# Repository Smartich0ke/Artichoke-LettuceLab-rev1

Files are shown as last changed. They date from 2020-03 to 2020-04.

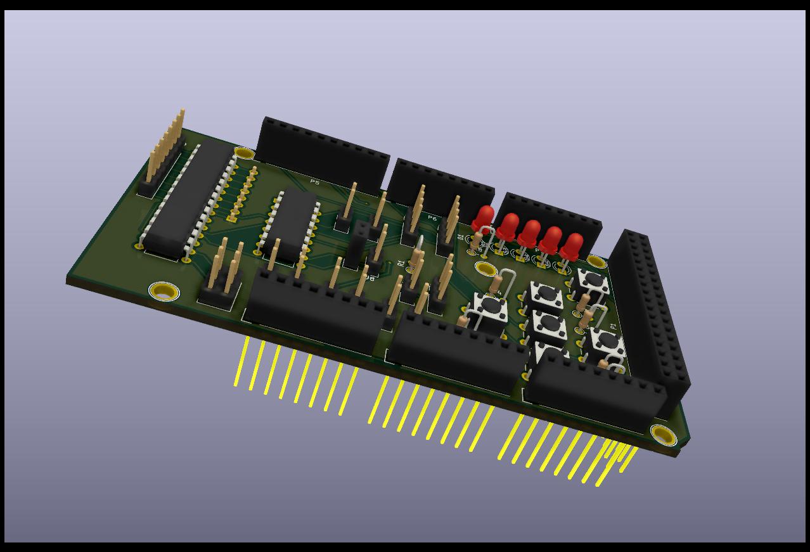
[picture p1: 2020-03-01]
pcb-files/megasheild.jpg

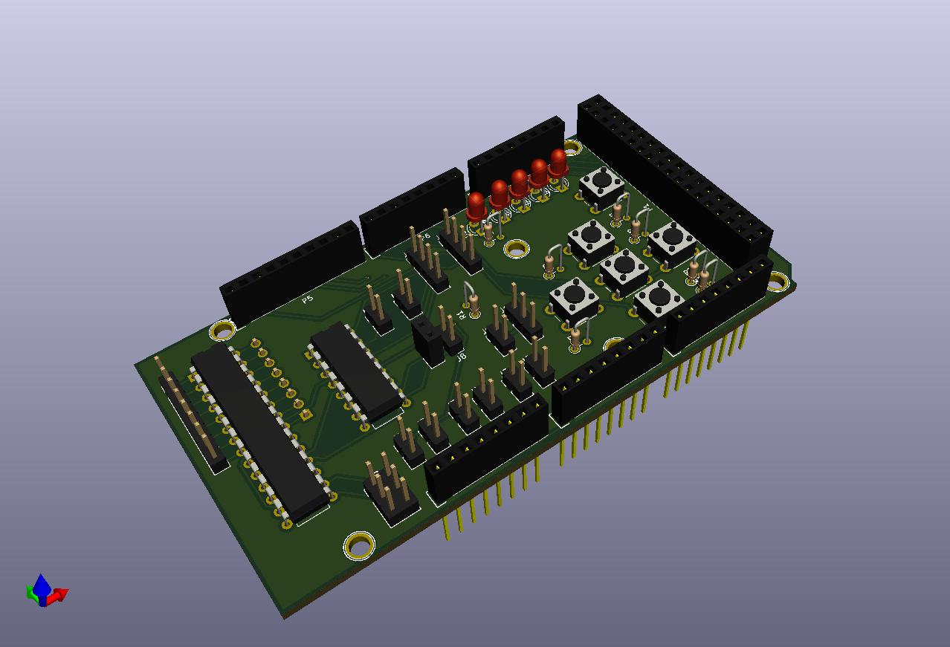
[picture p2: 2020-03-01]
pcb-files/megasheild5.jpg

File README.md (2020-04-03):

# Artichoke LettuceLab rev1

For more information please see my website at: https://hackaday.io/project/170160-artichoke-lettucelab-rev-10#header

Please feel free to join this repository if you are interested or email me at: pitsnthings@gmail.com

The Artichoke LettuceLab Arduino Mega sheild is designed to make the construction of small arduino robots much easier and less time consuming. It can drive 2 motors (or one stepper motor), a I2C interfaced LCD display, an ultrasonic distance sensor, an LDR sensor, 2 headlights, 2 blinkers, 2 tail lights, 5 LEDS, 6 buttons and it even includes a MCP23017 GPIO expander to give you another 16 I/O pins.

FILES:

lettucelab-master.zip : All nececarry gerber files compressed into a zip file.

pcb-files : all kicad pcb files, inside that is "gerbers1.0"  which has all the gerbers in it.

wheels1.0.ino : Example Arduino sketch for wheels and lights.

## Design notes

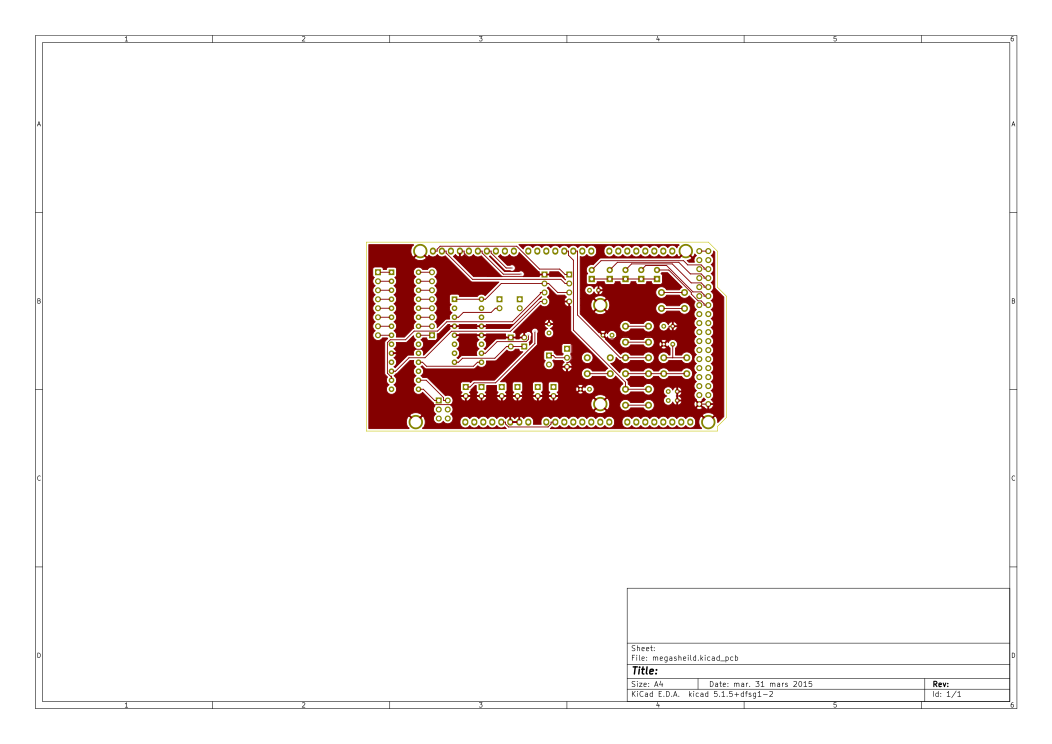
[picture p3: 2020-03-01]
pcb-files/megasheild-F_Cu.png

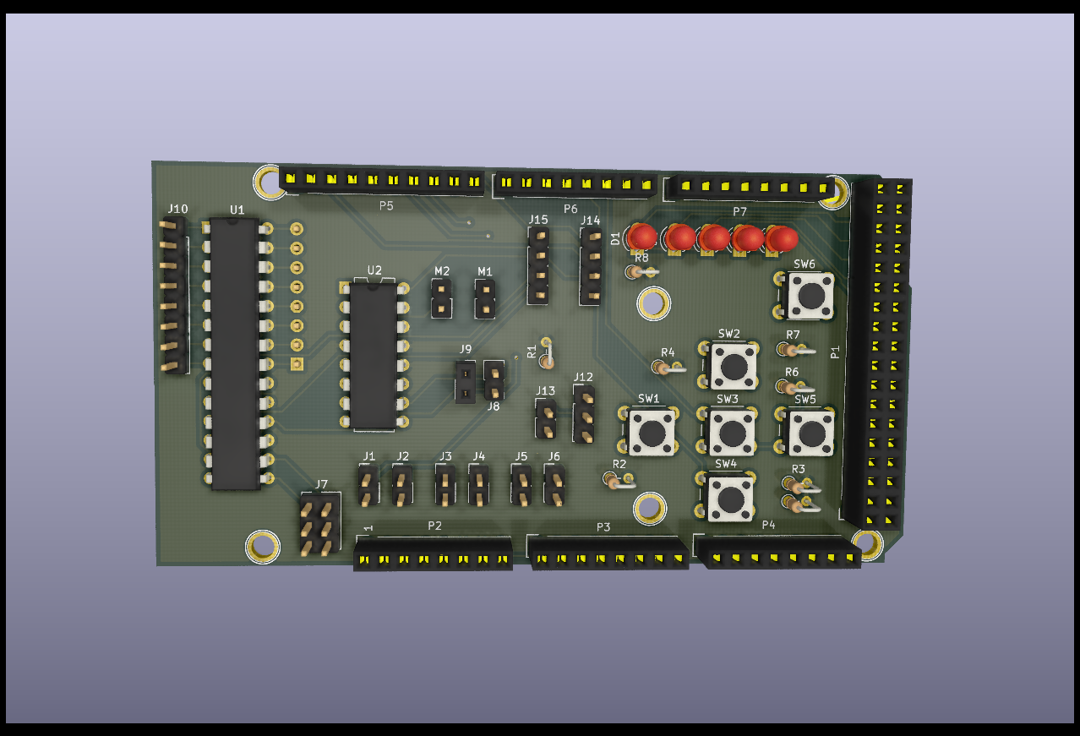
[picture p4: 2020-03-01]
pcb-files/megasheild3.png

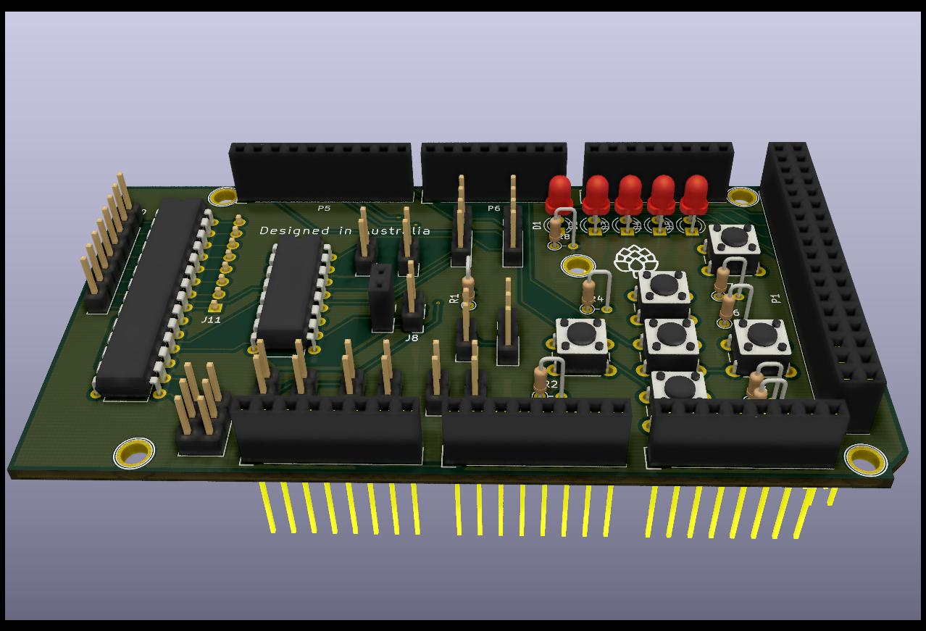
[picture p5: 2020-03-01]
pcb-files/background.jpg

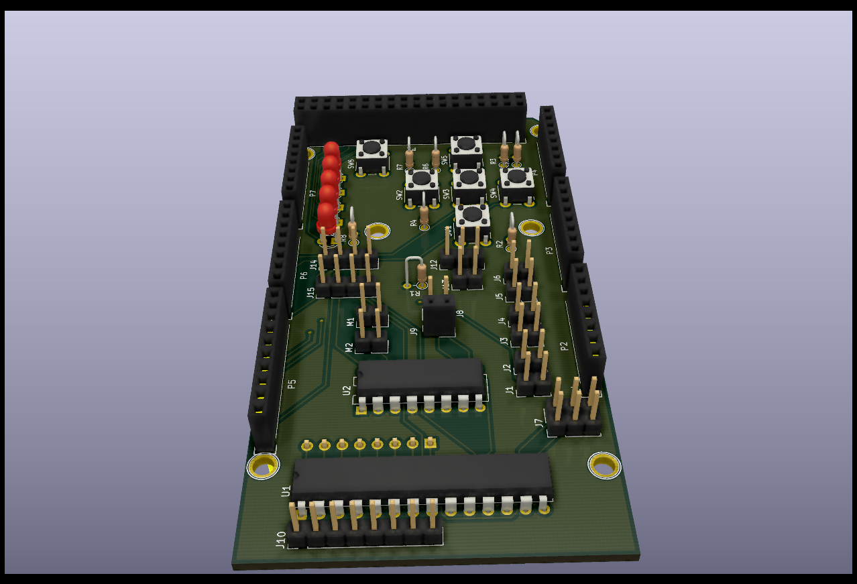
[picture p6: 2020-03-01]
pcb-files/megasheild2.png

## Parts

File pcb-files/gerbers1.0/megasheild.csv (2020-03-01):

Id | Designator | Package | Quantity | Designation | Supplier and ref
1 | G*** | 10 | 1 | LOGO
2 | U2 | DIP-16_W7.62mm | 1 | L293D
3 | P1 | Socket_Strip_Arduino_2x18 | 1 | Digital
4 | P2 | Socket_Strip_Arduino_1x08 | 1 | Power
5 | P3,P4 | Socket_Strip_Arduino_1x08 | 2 | Analog
6 | P5 | Socket_Strip_Arduino_1x10 | 1 | PWM
7 | P6 | Socket_Strip_Arduino_1x08 | 1 | PWM
8 | P7 | Socket_Strip_Arduino_1x08 | 1 | Communication
9 | P8,P9,P10,P11,P12,P13 | Arduino_1pin | 6 | CONN_01X01
10 | D1,D2,D3,D4,D5 | LED_D3.0mm | 5 | LED
11 | J1 | PinHeader_1x02_P2.54mm_Vertical | 1 | leftheadlight
12 | J2 | PinHeader_1x02_P2.54mm_Vertical | 1 | rightheadlight
13 | J3 | PinHeader_1x02_P2.54mm_Vertical | 1 | leftblinker
14 | J4 | PinHeader_1x02_P2.54mm_Vertical | 1 | rightblinker
15 | J5 | PinHeader_1x02_P2.54mm_Vertical | 1 | lefttaillight
16 | J6 | PinHeader_1x02_P2.54mm_Vertical | 1 | righttaillight
17 | J7 | PinHeader_2x03_P2.54mm_Vertical | 1 | Conn_02x03_Counter_Clockwise
18 | J8 | PinHeader_1x02_P2.54mm_Vertical | 1 | batt-conn1
19 | J9 | PinSocket_1x02_P2.54mm_Vertical | 1 | batt-conn2
20 | J10,J11 | PinHeader_1x08_P2.54mm_Vertical | 2 | Conn_01x08_Male
21 | J12 | PinHeader_1x03_P2.54mm_Vertical | 1 | distance1
22 | J13 | PinHeader_1x02_P2.54mm_Vertical | 1 | light1
23 | J14 | PinHeader_1x04_P2.54mm_Vertical | 1 | 12c
24 | J15 | PinHeader_1x04_P2.54mm_Vertical | 1 | screen port
25 | M1,M2 | PinHeader_1x02_P2.54mm_Vertical | 2 | Motor_DC
26 | R1,R2,R3,R4,R5,R6,R7,R8 | R_Axial_DIN0204_L3.6mm_D1.6mm_P2.54mm_Vertical | 8 | R
27 | SW1 | SW_PUSH_6mm | 1 | leftbutton
28 | SW2 | SW_PUSH_6mm | 1 | upbutton
29 | SW3 | SW_PUSH_6mm | 1 | centerbutton
30 | SW4 | SW_PUSH_6mm | 1 | downbutton
31 | SW5 | SW_PUSH_6mm | 1 | rightbutton
32 | SW6 | SW_PUSH_6mm | 1 | SW_Push
33 | U1 | DIP-28_W7.62mm | 1 | MCP23017_SP

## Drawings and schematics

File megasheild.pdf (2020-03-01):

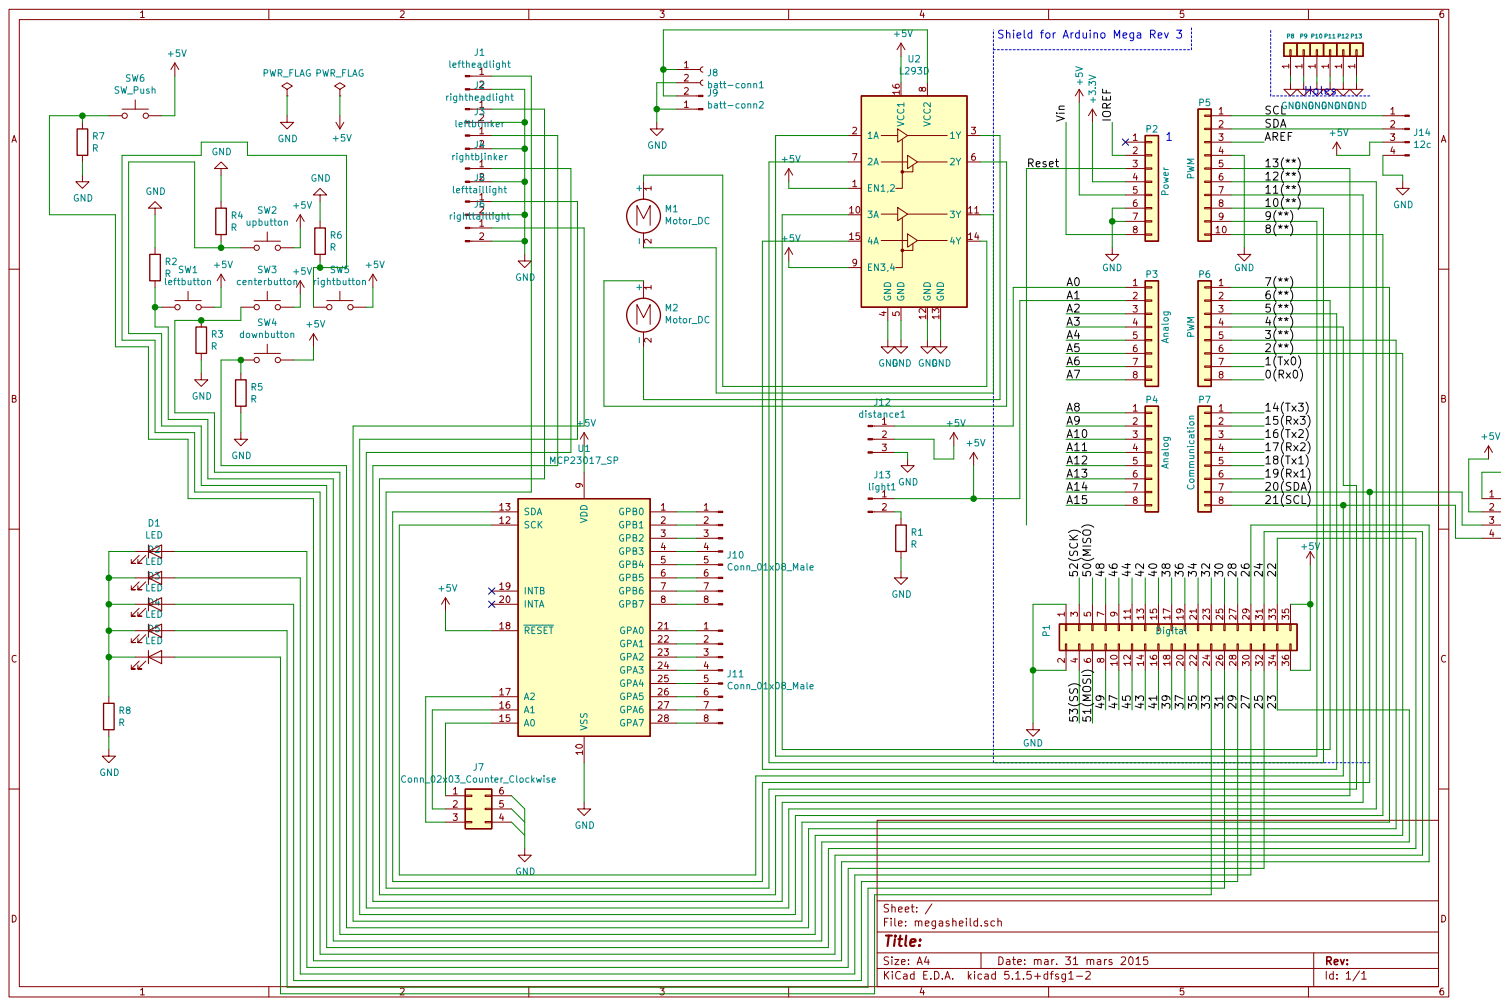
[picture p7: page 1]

Shield for Arduino Mega Rev 3
GND +5V

File: megasheild.sch Sheet: /
Id: 1/1 Title:

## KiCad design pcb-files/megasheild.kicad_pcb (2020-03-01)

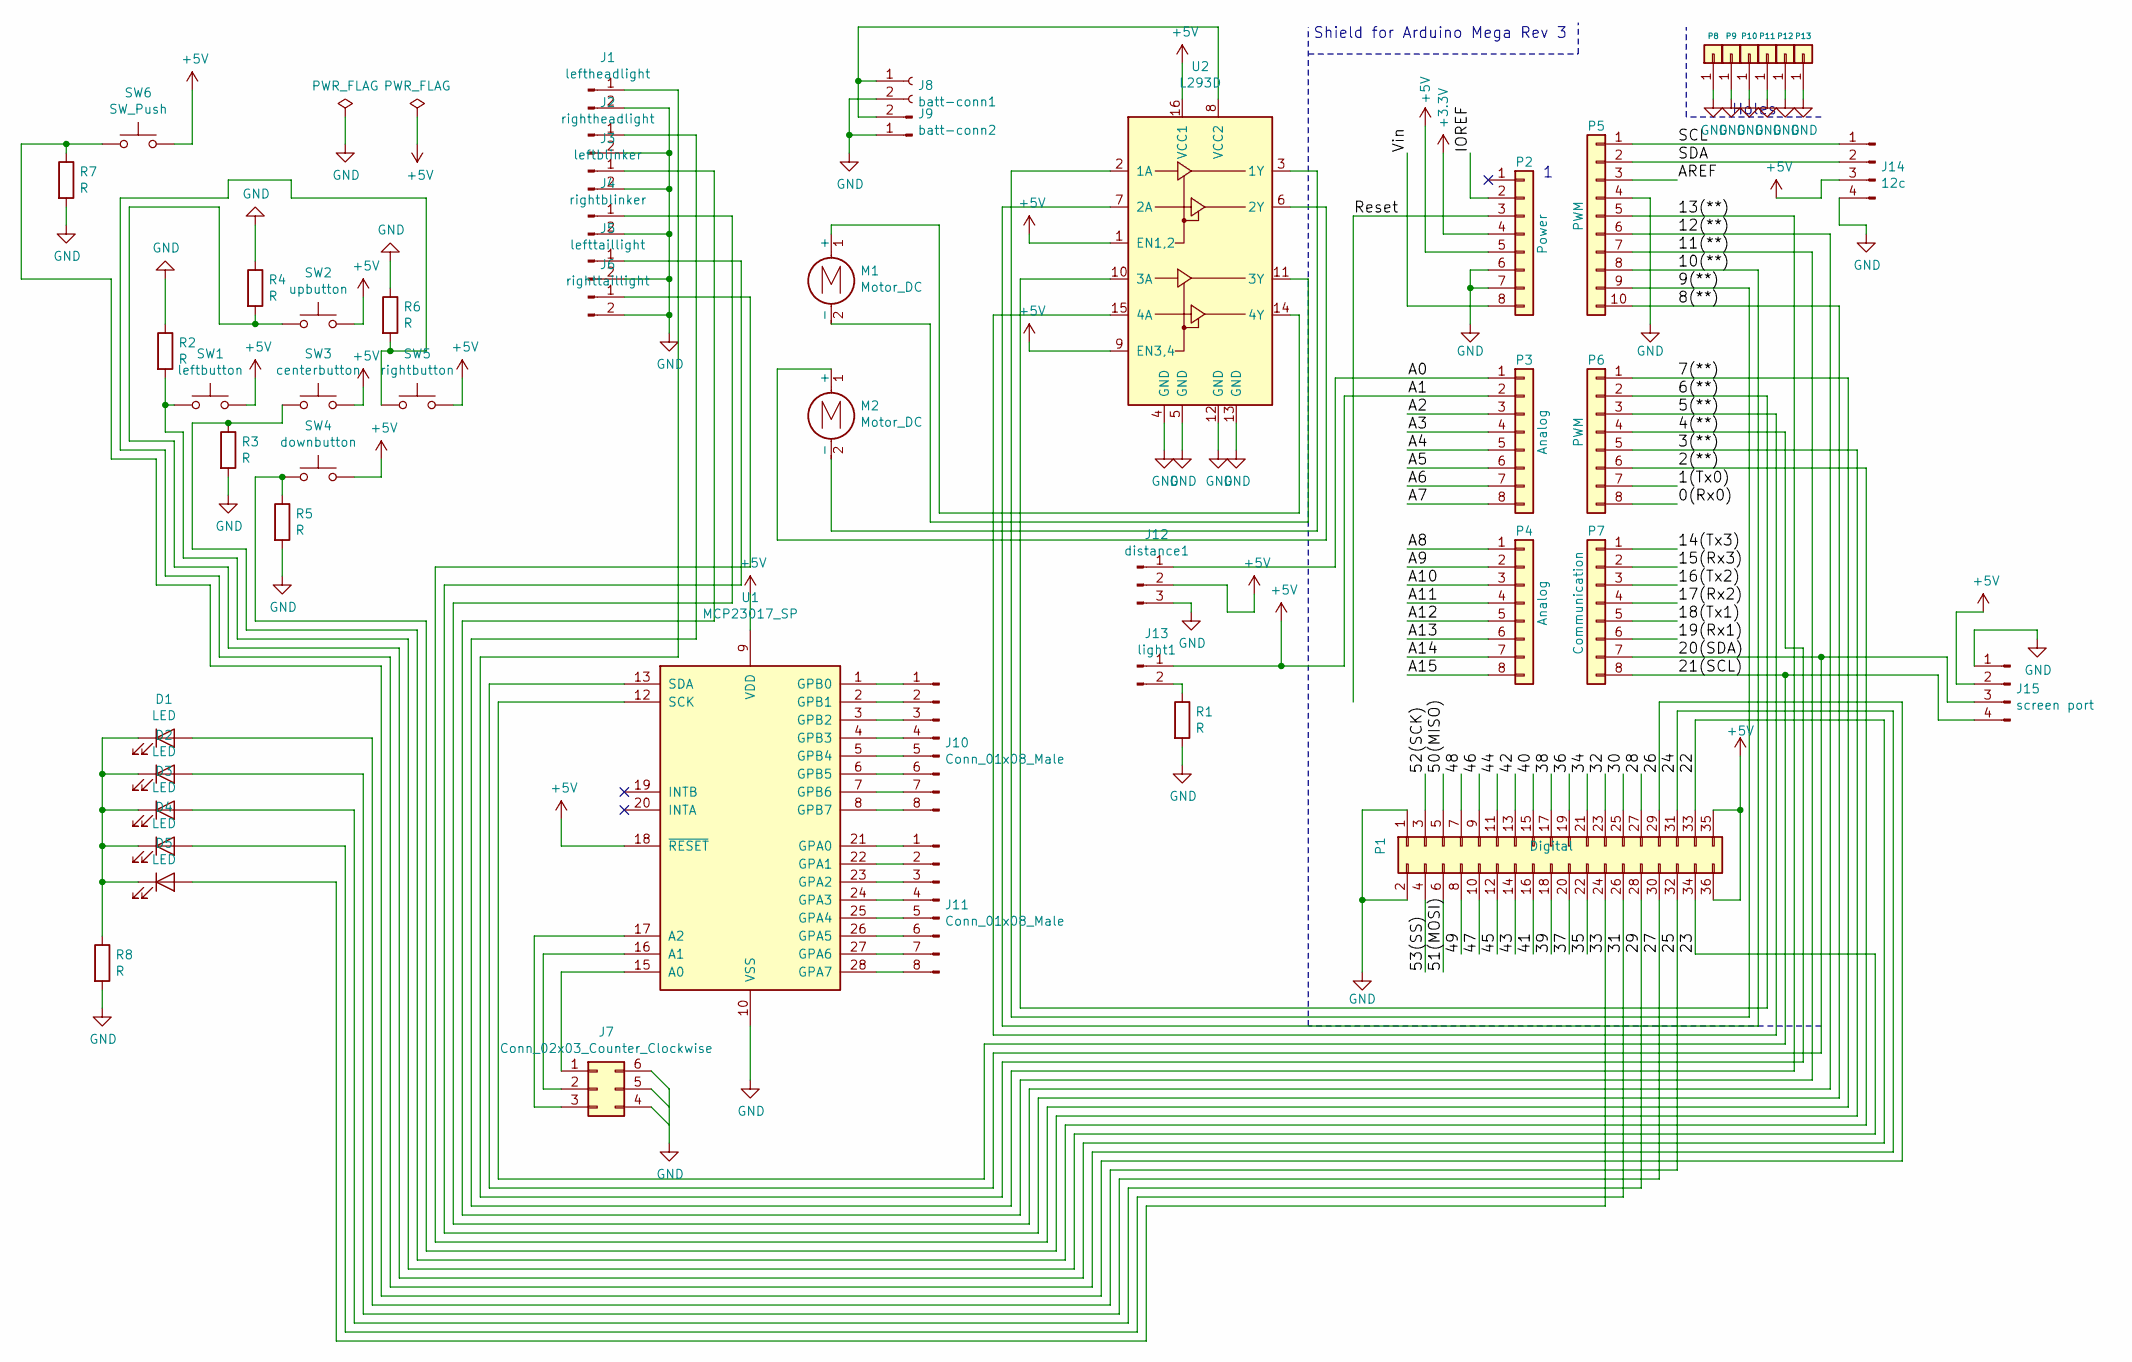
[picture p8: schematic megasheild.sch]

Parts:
D1, D2, D3, D4, D5: LED; LED_D3.0mm
J1: leftheadlight; PinHeader_1x02_P2.54mm_Vertical
J2: rightheadlight; PinHeader_1x02_P2.54mm_Vertical
J3: leftblinker; PinHeader_1x02_P2.54mm_Vertical
J4: rightblinker; PinHeader_1x02_P2.54mm_Vertical
J5: lefttaillight; PinHeader_1x02_P2.54mm_Vertical
J6: righttaillight; PinHeader_1x02_P2.54mm_Vertical
J7: Conn_02x03_Counter_Clockwise; PinHeader_2x03_P2.54mm_Vertical
J8: batt-conn1; PinHeader_1x02_P2.54mm_Vertical
J9: batt-conn2; PinSocket_1x02_P2.54mm_Vertical
J10, J11: Conn_01x08_Male; PinHeader_1x08_P2.54mm_Vertical
J12: distance1; PinHeader_1x03_P2.54mm_Vertical
J13: light1; PinHeader_1x02_P2.54mm_Vertical
J14: 12c; PinHeader_1x04_P2.54mm_Vertical
J15: screen port; PinHeader_1x04_P2.54mm_Vertical
M1, M2: Motor_DC; PinHeader_1x02_P2.54mm_Vertical
P1: Digital; Socket_Strip_Arduino_2x18
P2: Power; Socket_Strip_Arduino_1x08
P3, P4: Analog; Socket_Strip_Arduino_1x08
P5: PWM; Socket_Strip_Arduino_1x10
P6: PWM; Socket_Strip_Arduino_1x08
P7: Communication; Socket_Strip_Arduino_1x08
P8, P9, P10, P11, P12, P13: CONN_01X01; Arduino_1pin
R1, R2, R3, R4, R5, R6, R7, R8: R; R_Axial_DIN0204_L3.6mm_D1.6mm_P2.54mm_Vertical
SW1: leftbutton; SW_PUSH_6mm
SW2: upbutton; SW_PUSH_6mm
SW3: centerbutton; SW_PUSH_6mm
SW4: downbutton; SW_PUSH_6mm
SW5: rightbutton; SW_PUSH_6mm
SW6: SW_Push; SW_PUSH_6mm
U1: MCP23017_SP; DIP-28_W7.62mm
U2: L293D; DIP-16_W7.62mm

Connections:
+3V3: P2.4
+5V: J12.2, J13.1, J14.3, J15.2, P1.35, P1.36, P2.5, P3.2, SW1.2, SW2.2, SW3.2, SW4.2, SW5.2, SW6.2, U1.9 (VDD), U1.18 (~RESET~), U2.1 (EN1,2), U2.9 (EN3,4), U2.16 (VCC1)
/0(Rx0): P6.8
/1(Tx0): P6.7
/2(**): P6.6, R3.1, SW3.1
/3(**): P6.5, R5.1, SW4.1
/4(**): J1.1, P6.4
/5(**): P6.3, U2.15 (4A)
/6(**): P6.2, U2.10 (3A)
/7(**): J6.1, P6.1
/8(**): J5.1, P5.10
/9(**): P5.9, U2.2 (1A)
/10(**): P5.8, U2.7 (2A)
/11(**): J3.1, P5.7
/12(**): J4.1, P5.6
/13(**): J2.1, P5.5
/14(Tx3): P7.1
/15(Rx3): P7.2
/16(Tx2): P7.3
/17(Rx2): P7.4
/18(Tx1): P7.5
/19(Rx1): P7.6
/20(SDA): J15.3, P7.7, U1.13 (SDA)
/21(SCL): J15.4, P7.8, U1.12 (SCK)
/22: P1.33, R4.2, SW2.1
/23: P1.34, R2.2, SW1.1
/24: P1.31, R6.2, SW5.1
/25: D1.2 (A), P1.32
/26: P1.29, R7.1, SW6.1
/27: D2.2 (A), P1.30
/28: P1.27
/29: D3.2 (A), P1.28
/30: P1.25
/31: D4.2 (A), P1.26
/32: P1.23
/33: D5.2 (A), P1.24
/34: P1.21
/35: P1.22
/36: P1.19
/37: P1.20
/38: P1.17
/39: P1.18
/40: P1.15
/41: P1.16
/42: P1.13
/43: P1.14
/44: P1.11
/45: P1.12
/46: P1.9
/47: P1.10
/48: P1.7
/49: P1.8
/50(MISO): P1.5
/51(MOSI): P1.6
/52(SCK): P1.3
/53(SS): P1.4
/A0: J12.1, P3.1
/A2: P3.3
/A3: P3.4
/A4: P3.5
/A5: P3.6
/A6: P3.7
/A7: P3.8
/A8: P4.1
/A9: P4.2
/A10: P4.3
/A11: P4.4
/A12: P4.5
/A13: P4.6
/A14: P4.7
/A15: P4.8
/AREF: P5.3
/IOREF: P2.2
/Reset: P2.3
/SCL: J14.1, P5.1
/SDA: J14.2, P5.2
/Vin: P2.8
GND: J1.2, J2.2, J3.2, J4.2, J5.2, J6.2, J8.2, J9.1, J12.3, J14.4, J15.1, P1.1, P1.2, P2.6, P2.7, P5.4, P8.1, P9.1, P10.1, P11.1, P12.1, P13.1, R1.2, R2.1, R3.2, R4.1, R5.2, R6.1, R7.2, R8.2, U1.10 (VSS), U2.4 (GND), U2.5 (GND), U2.12 (GND), U2.13 (GND)
unnamed: D1.1 (K), D2.1 (K), D3.1 (K), D4.1 (K), D5.1 (K), R8.1
unnamed: J7.1, U1.15 (A0)
unnamed: J7.2, U1.16 (A1)
unnamed: J7.3, U1.17 (A2)
unnamed: J8.1, J9.2, U2.8 (VCC2)
unnamed: J10.1, U1.1 (GPB0)
unnamed: J10.2, U1.2 (GPB1)
unnamed: J10.3, U1.3 (GPB2)
unnamed: J10.4, U1.4 (GPB3)
unnamed: J10.5, U1.5 (GPB4)
unnamed: J10.6, U1.6 (GPB5)
unnamed: J10.7, U1.7 (GPB6)
unnamed: J10.8, U1.8 (GPB7)
unnamed: J11.1, U1.21 (GPA0)
unnamed: J11.2, U1.22 (GPA1)
unnamed: J11.3, U1.23 (GPA2)
unnamed: J11.4, U1.24 (GPA3)
unnamed: J11.5, U1.25 (GPA4)
unnamed: J11.6, U1.26 (GPA5)
unnamed: J11.7, U1.27 (GPA6)
unnamed: J11.8, U1.28 (GPA7)
unnamed: J13.2, R1.1
unnamed: M1.1 (+), U2.14 (4Y)
unnamed: M1.2 (-), U2.11 (3Y)
unnamed: M2.1 (+), U2.6 (2Y)
unnamed: M2.2 (-), U2.3 (1Y)

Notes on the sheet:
Shield for Arduino Mega Rev 3
Holes

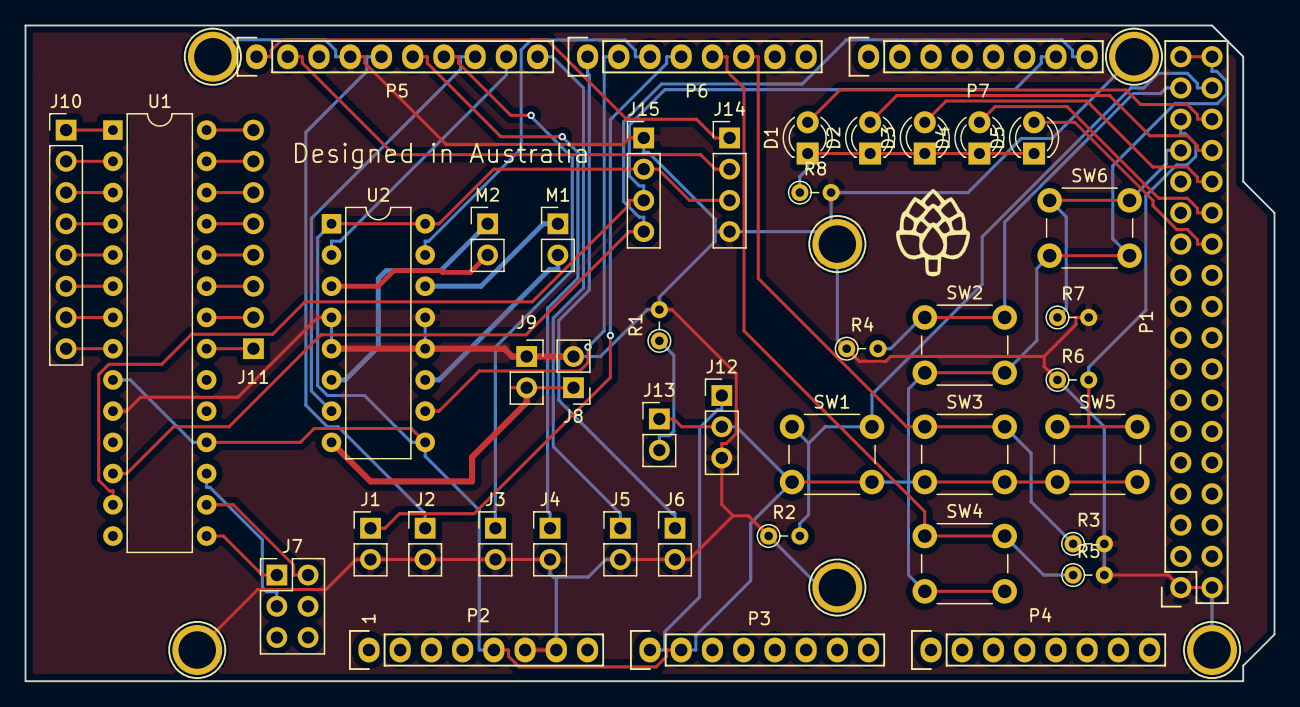
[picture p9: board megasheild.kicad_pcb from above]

Board: 2 copper layers, 101.6 x 53.3 mm, 51 parts (1 on the bottom side), 54 nets.

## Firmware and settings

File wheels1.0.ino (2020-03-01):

/*
 * Wheels 1.0.1
 * 
 * Written by Nikolai Patrick
 * ##########################
 * 
 * A sketch for an automated vehicle driving two motors, 
 * headlights, indicator lights and tail lights automated with
 * an LDR sensor. It also includes support for an analog ultrasonic
 * distance sensor and a rear one in the future. The vehicle detects
 * when it gets close to a wall then backs out and turns around until
 * it hits another wall. The motors are driven by an L239D and will
 * be able to track lines in the future with a GY - 31 colour module.
 * 
 * You may use, modify, and re-distribute this code under the terms
 * of the GNU GPL 3.0 General Public Licence
 * https://www.gnu.org/licenses/gpl-3.0.html
 * 
 */
int DevisedLeft;
int DevisedForward;
int DevisedBackward;
int DevisedRight;
int DistanceValue;
int DiceRoll;
int LightValue;
int LeftHeadLight = 4;
int RightHeadLight = 13;
int LeftBlinker = 11;
int RightBlinker = 12;
int LeftTailLight = 8;
int RightTailLight = 7;
void DisableAll() { //Turn off all motors
  digitalWrite(10, LOW);//D10- right forward
  digitalWrite(9, LOW); //D9 - right backward
  digitalWrite(6, LOW); //D6 - left backward
  digitalWrite(5, LOW); //D5 - left forward
}
void MoveForward(int ForwardLength, int ForwardSpeed) { //Move the vehicle forwards (seconds, speed)
  analogWrite(5, ForwardSpeed);
  analogWrite(10, ForwardSpeed);
  DevisedForward = ForwardLength;
  delay(DevisedForward);
  analogWrite(5, 0);
  analogWrite(10, 0);
}
void MoveBackward(int BackwardLength, int BackwardSpeed) { //Move the vehicle backwards (seconds, speed)
  analogWrite(6, BackwardSpeed);
  analogWrite(9, BackwardSpeed);
  DevisedBackward = BackwardLength * 1000;
  delay(DevisedBackward);
  analogWrite(6, 0);
  analogWrite(9, 0);
}
void MoveLeft(int LeftLength, int LeftSpeed) { //Turn the vehicle left (seconds, speed)
  analogWrite(6, LeftSpeed);
  analogWrite(10, LeftSpeed);
  DevisedLeft = LeftLength * 1000;
  delay(DevisedLeft);
  analogWrite(6, 0);
  analogWrite(10, 0);
}
void MoveRight(int RightLength, int RightSpeed) { //Turn the vehicle right (seconds, speed)
  analogWrite(5, RightSpeed);
  analogWrite(9, RightSpeed);
  DevisedRight = RightLength * 1000;
  delay(DevisedRight);
  analogWrite(5, 0);
  analogWrite(9, 0);
}
void MoveLeftOrRight(int LeftOrRightSpeed) {
  DiceRoll = random(1, 2);
  if (DiceRoll==1) {
    MoveLeft(LeftOrRightSpeed, 255);
  }
  if (DiceRoll==2) {
    MoveRight(LeftOrRightSpeed, 255);
  }
}
void LightsOff() {
  analogWrite(LeftHeadLight, 0);
  analogWrite(RightHeadLight, 0);
  analogWrite(LeftBlinker, 0);
  analogWrite(RightBlinker, 0);
  analogWrite(LeftTailLight, 0);
  analogWrite(RightTailLight, 0);
}
void LightsOn(int allbrightness) {
  analogWrite(LeftHeadLight, allbrightness);
  analogWrite(RightHeadLight, allbrightness);
  analogWrite(LeftBlinker, allbrightness);
  analogWrite(RightBlinker, allbrightness);
  analogWrite(LeftTailLight, allbrightness);
  analogWrite(RightTailLight, allbrightness);
}
void HeadLightsOn(int headbrightness) {
  analogWrite(LeftHeadLight, headbrightness);
  analogWrite(RightHeadLight, headbrightness)
}
void HeadLightsOff() {
  analogWrite(LeftHeadLight, 0);
  analogWrite(RightHeadLight, 0)
}
void TailLightsOn(int tailbrightness) {
  analogWrite(LeftTailLight, tailbrightness);
  analogWrite(RightTailLight, tailbrightness);
}
void TailLightsOff() {
  analogWrite(LeftTailLight, 0);
  analogWrite(RightTailLight, 0);
}
void HazardsOn(int hazardbrightness, int hazardtime) {
  for(int hazardcount; hazardcount < hazardtime; hazardcount++) {
  analogWrite(LeftBlinker, allbrightness);
  analogWrite(RightBlinker, allbrightness);
  delay(500);
  analogWrite(LeftBlinker, 0);
  analogWrite(RightBlinker, 0);
  delay(500);
  }
}
void setup() {
  Serial.begin(9600);
  LightsOn(255);
}

void loop() {
  delay(1000);
  LightValue = analogRead(A1);
  DistanceValue = analogRead(A0);
  Serial.println(LightValue);
  if (DistanceValue > 590) {
   MoveBackward(2, 255);
   MoveLeftOrRight(2);
  }
  MoveForward(10, 255);
}

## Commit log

2020-03-01 added gerbers
2020-03-01 all pcb files
    [megasheild-B_Cu.gbr, megasheild-B_Mask.gbr, megasheild-B_SilkS.gbr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]
2020-03-01 added arduino sketch
2020-04-04 added schematic
